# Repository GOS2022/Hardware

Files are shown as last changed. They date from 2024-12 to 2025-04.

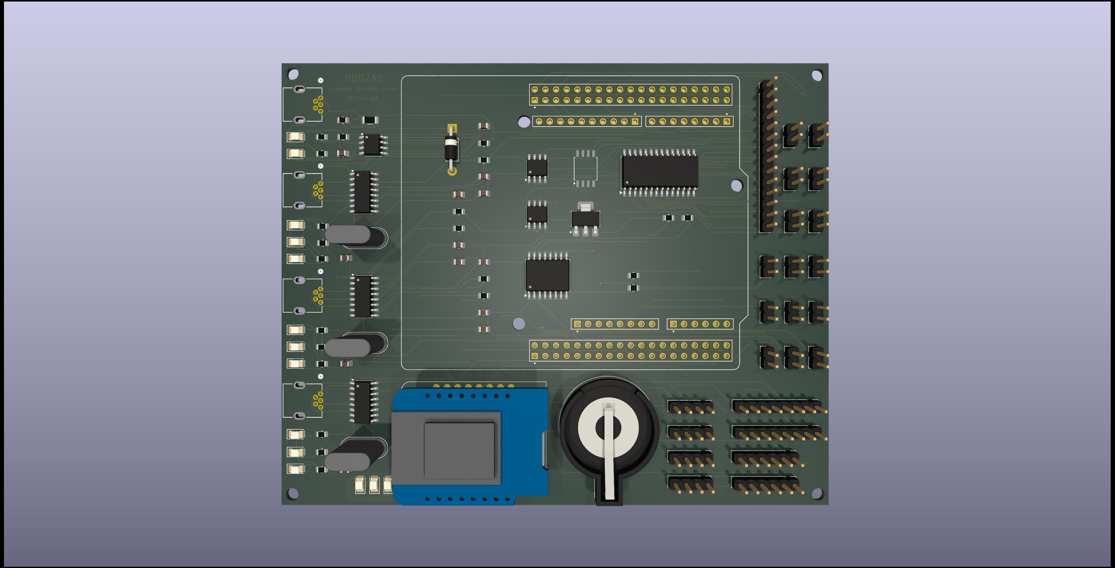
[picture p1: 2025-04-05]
MB02A1/03_Production/mb02a1_pcb_3d.jpg

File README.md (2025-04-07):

# Hardware
This repository contains the design and production files of hardware projects.

# Description
The main goal of hardware projects is to create a compact test device for the OS and service tests.

# Remarks
Contribution to this project is encouraged and appriciated.
If you have any questions or ideas, feel free to contact me: ahmedibrahim.gazar97@gmail.com

Last updated: 2025-04-07
(c) 2025, Ahmed Gazar

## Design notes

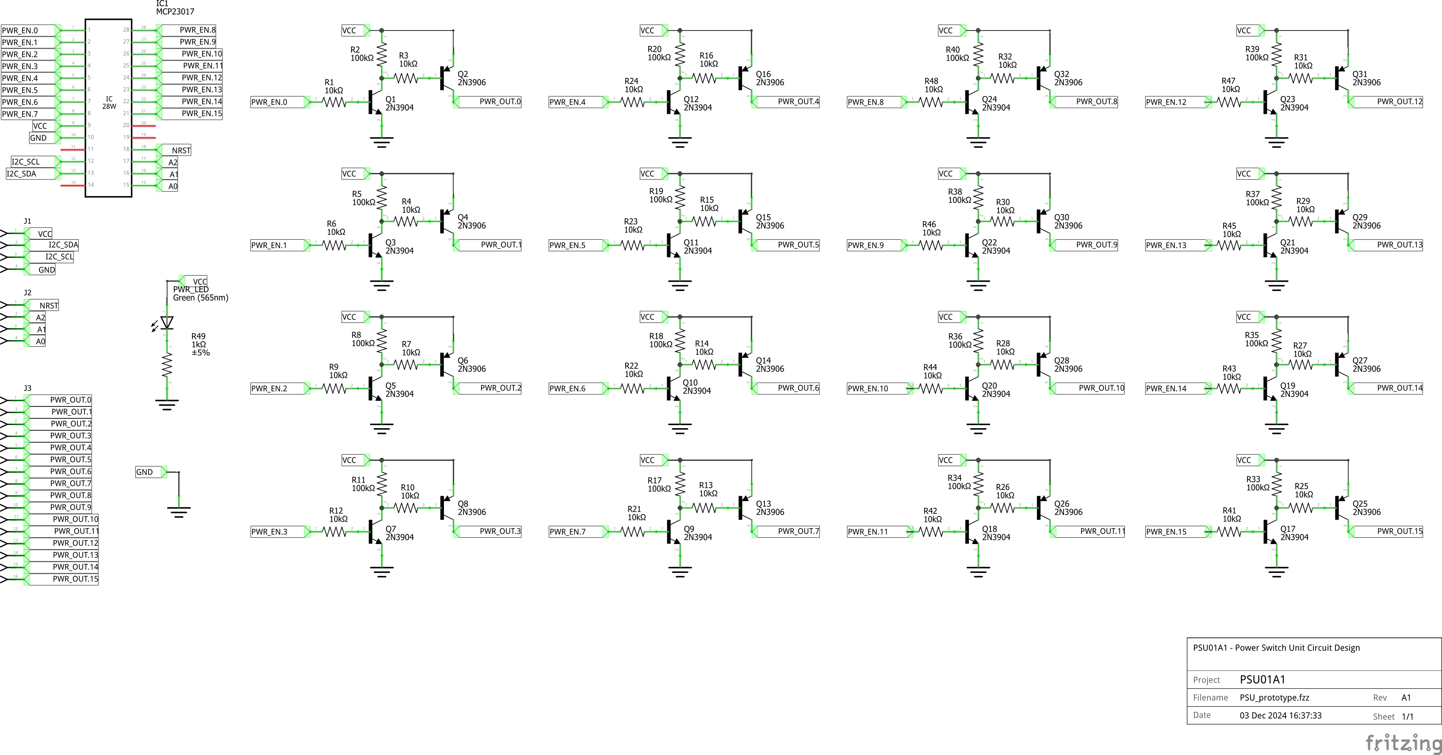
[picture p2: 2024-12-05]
MB02A1/02_Prototyping_phase/PowerSwitchUnit_prototype/Schematic.png

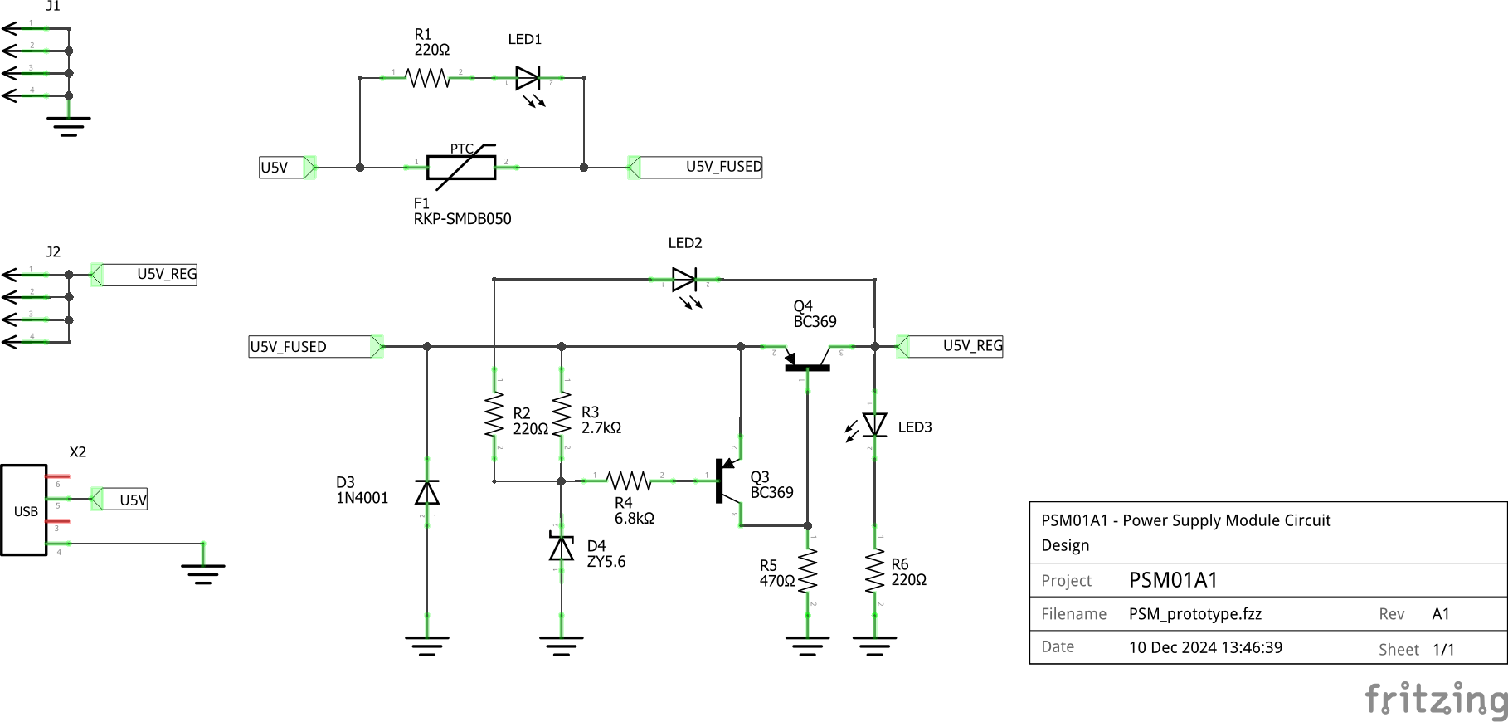
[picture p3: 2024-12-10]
MB02A1/02_Prototyping_phase/PowerSupplyModule_prototype/Schematic.png

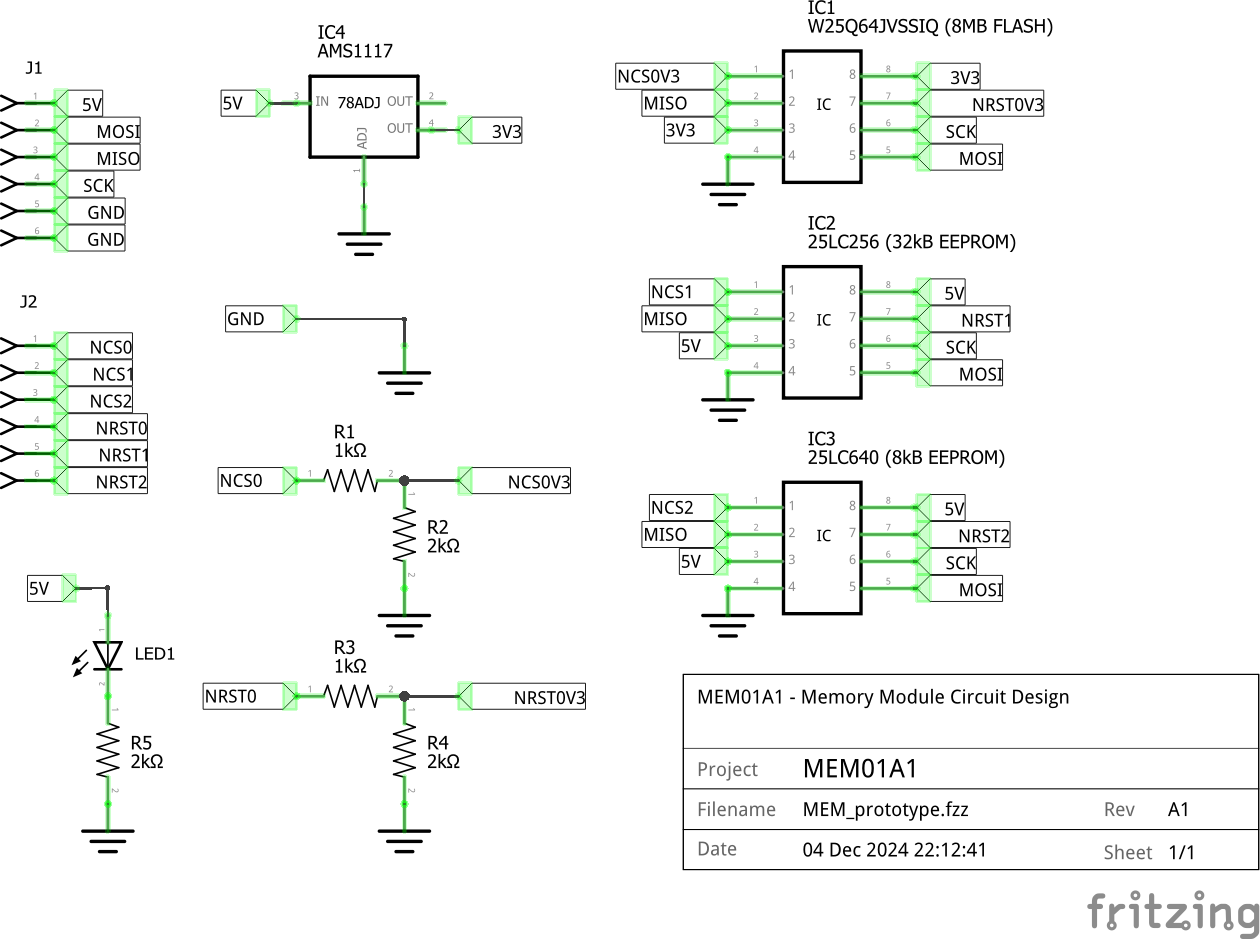
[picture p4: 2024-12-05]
MB02A1/02_Prototyping_phase/MemoryModule_prototype/Schematic.png

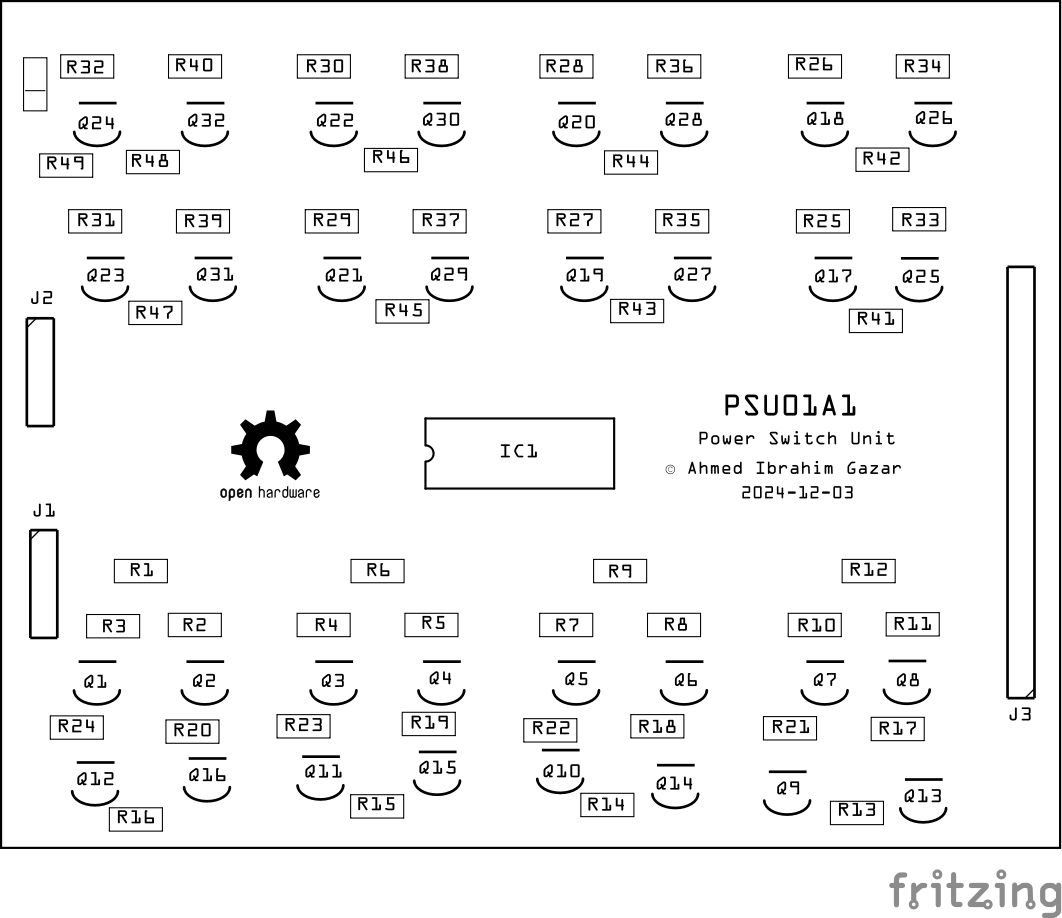
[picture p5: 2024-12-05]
MB02A1/02_Prototyping_phase/PowerSwitchUnit_prototype/PCB_SilkScreenTop.png

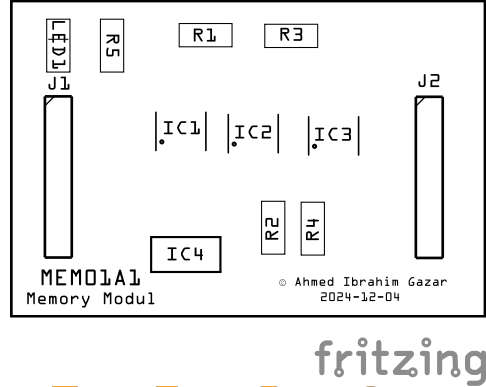
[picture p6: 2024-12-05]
MB02A1/02_Prototyping_phase/MemoryModule_prototype/PCB_SilkScreenTop.png

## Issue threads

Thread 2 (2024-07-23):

Main Board bugfix

agazar97, 2024-07-23:
Main Board (MB02A1) shall be developed based on the design of MB01A1 with the following requirements:
- MB02A1 shall reuse elements of MB01A1 but cannot contain through-hole components (all components shall be surface mounted)
- MB02A1 shall reduce size compared to MB01A1
- MB02A1 shall only have one on-board IO extender instead of two, and the connector pin header type shall be replaced with a standard-distance one (MCP23017)
- MB02A1 shall only have one on-board FLASH memory chip instead of two (24LC256)
- MB02A1 shall have the I2C2 line fixed (it is not working on MB01A1)
- MB02A1 shall feature power line switches on all peripheries (VCC shall be controllable (on/off) for MCP23017, 24LC256, WeMos D1 mini, and display).
- MB02A1 shall not have pin header connectors for UART lines
- MB02A1 shall fix the issue with USART2 line
- MB02A1 shall fix the issue with UART power line feedback LEDs (they should only light up when a cable is connected)

Closed 2025-07-29.

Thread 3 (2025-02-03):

Power supply circuit test and rework (voltage drop issue)

gaborr971, 2025-02-03:

gaborr971, 2025-03-21:
Redesign is needed (simplification).

Closed 2025-03-21.

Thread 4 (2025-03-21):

Wemos trace output test (software serial)

gaborr971, 2025-03-21:

gaborr971, 2025-03-21:
Software serial added to pins D1 and D2. With an external converter, functionality has been tested. This configuration shall be used for new main board revision.

Closed 2025-03-22.

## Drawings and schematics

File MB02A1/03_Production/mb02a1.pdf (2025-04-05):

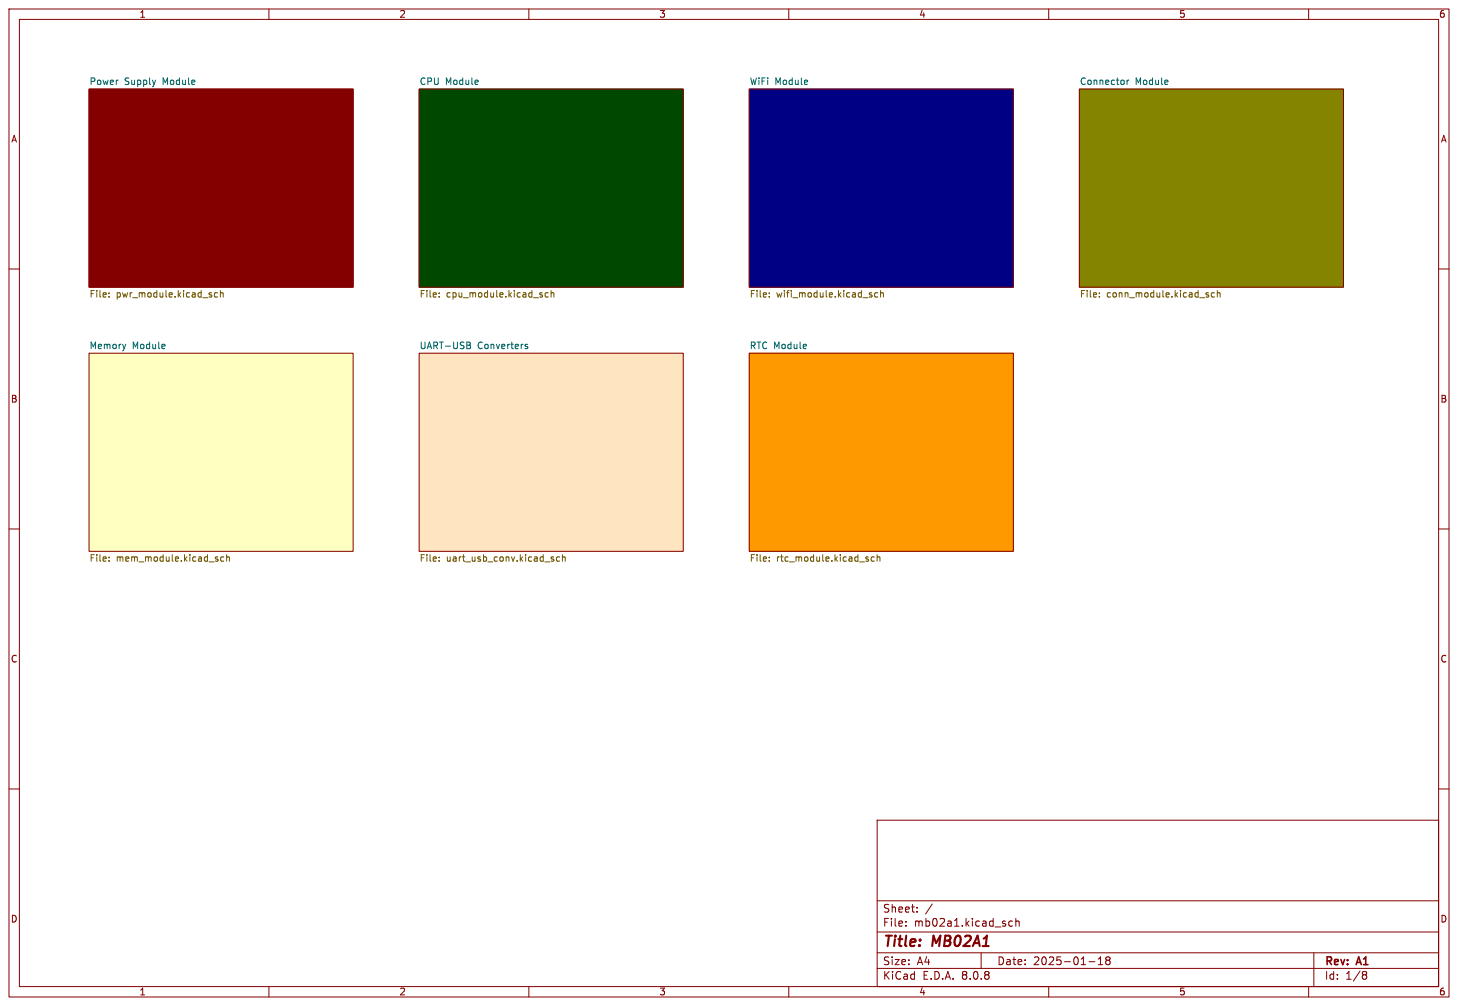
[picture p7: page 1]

Power Supply Module File: pwr_module.kicad_sch

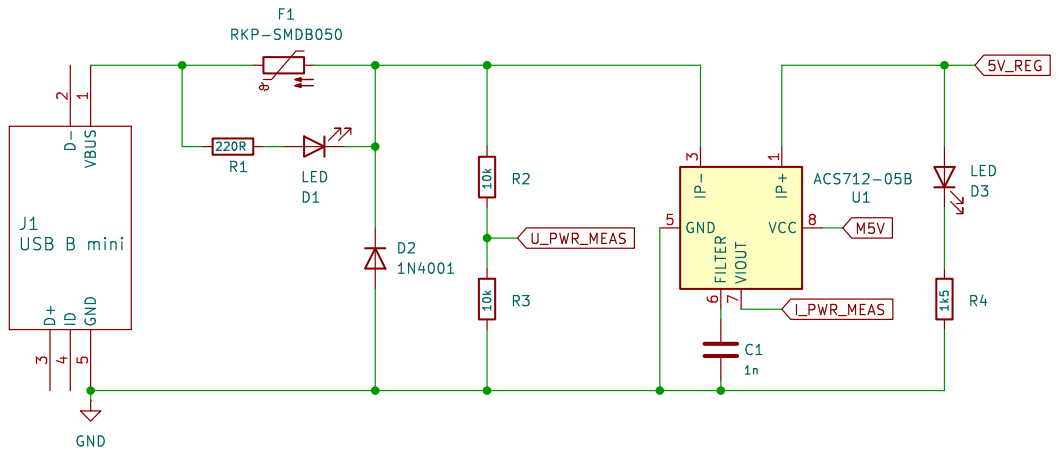
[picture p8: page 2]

Id: 2/8 Title: MB02A1 - Power Supply Module

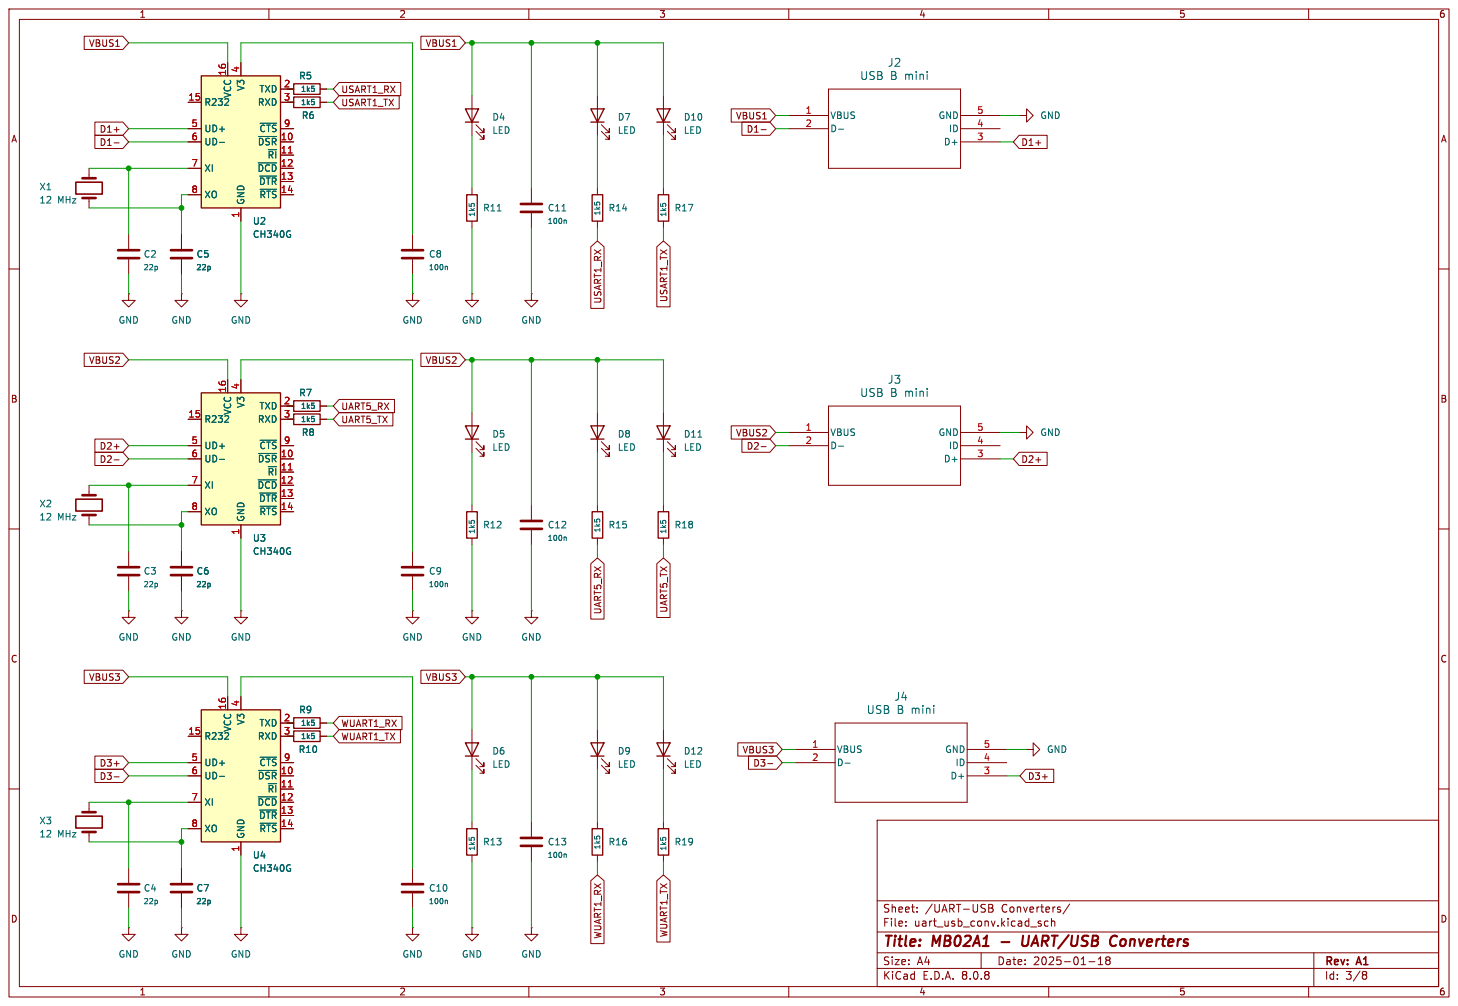
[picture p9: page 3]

Id: 3/8 Title: MB02A1 - UART/USB Converters

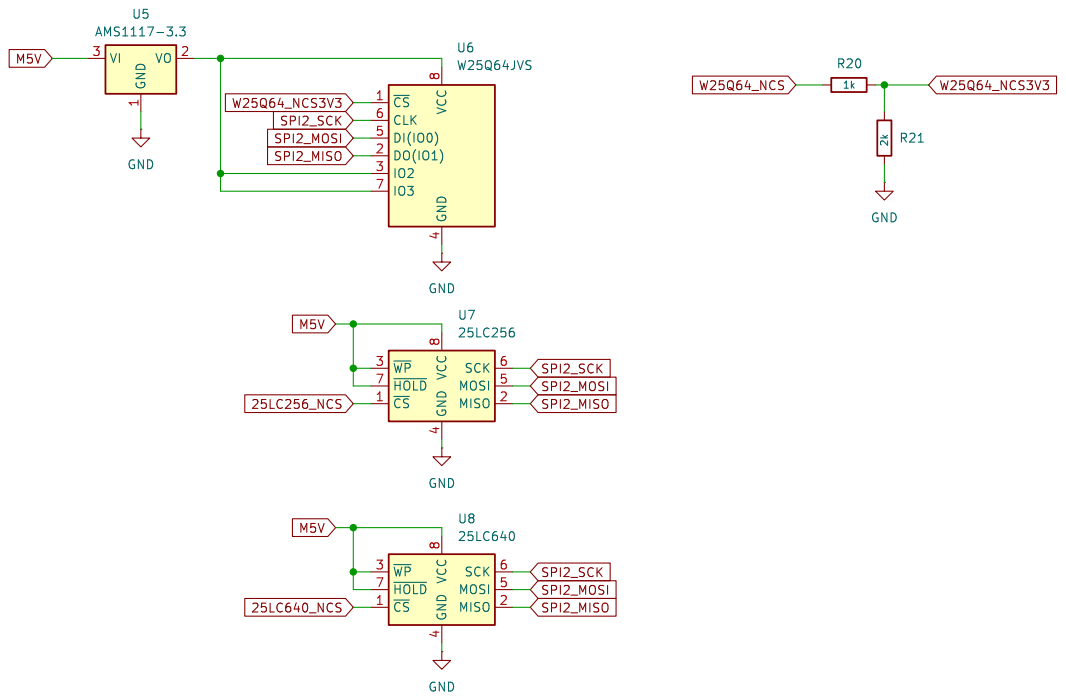
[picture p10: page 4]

1 VO 2 VI 3 U5 AMS1117-3.3 ~{CS} 1 MISO 2 ~{WP} 3 GND
SPI2_MISO W25Q64_NCS3V3 SPI2_MOSI M5V M5V

4 MOSI 5 SCK 6 ~{HOLD} 7 VCC

Id: 4/8 Title: MB02A1 - Memory Module

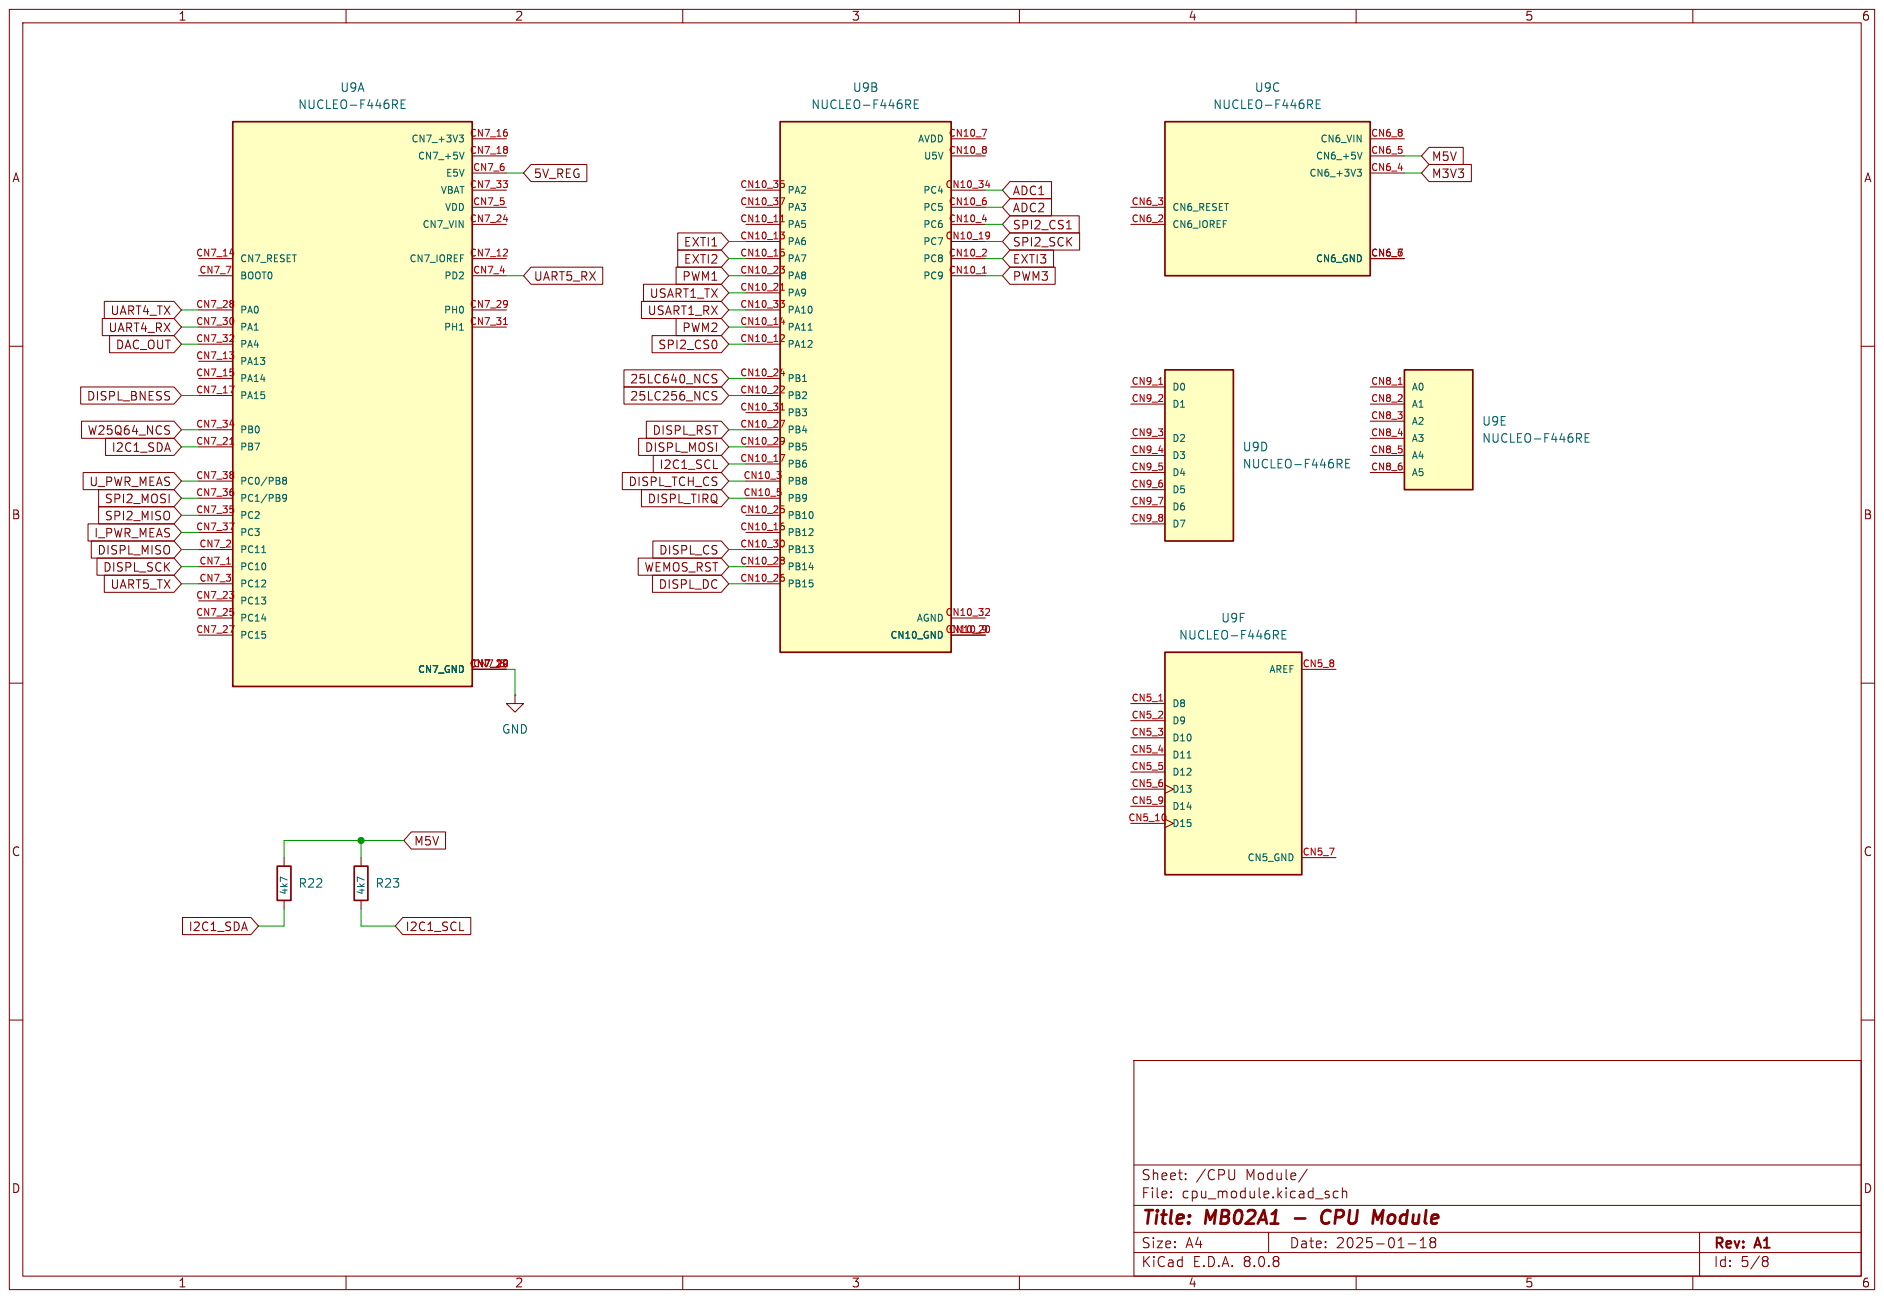
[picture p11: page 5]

Id: 5/8 Title: MB02A1 - CPU Module

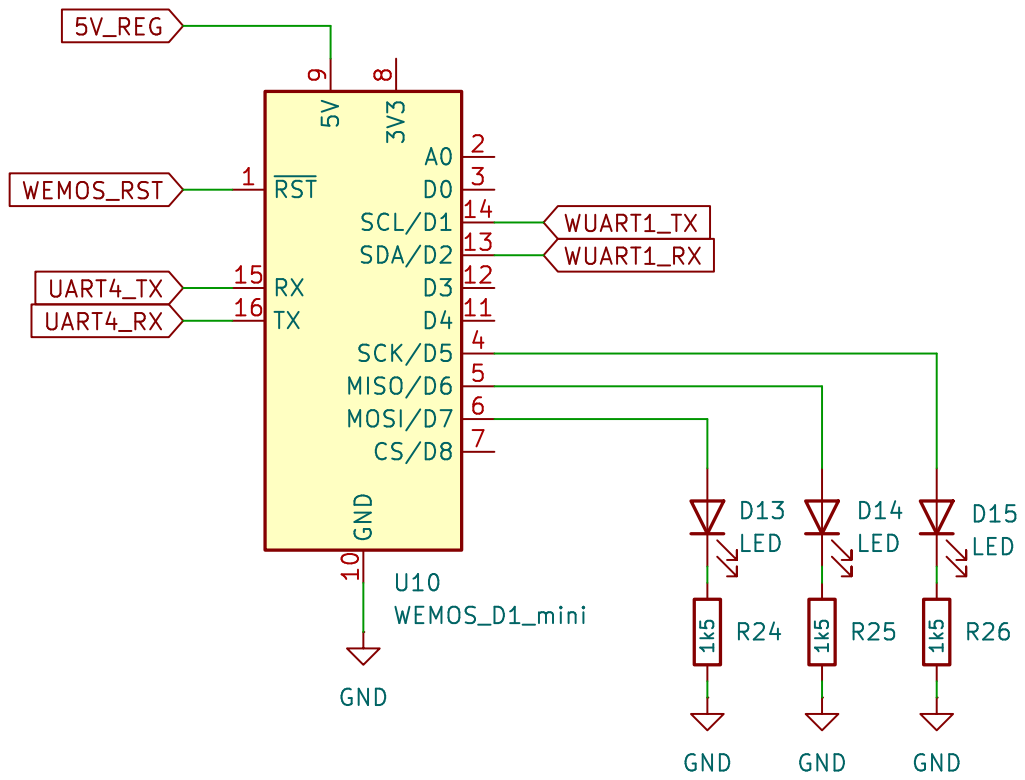
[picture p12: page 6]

Id: 6/8 Title: MB02A1 - WiFi Module

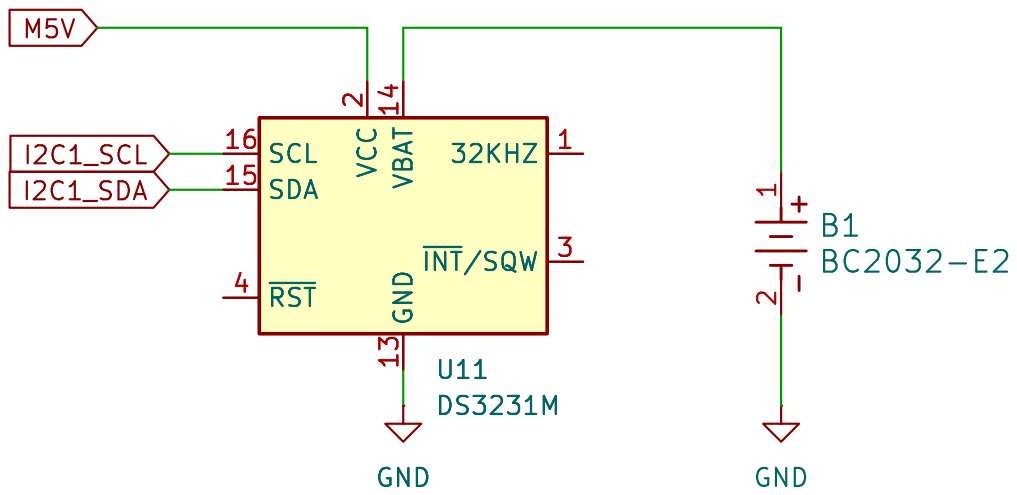
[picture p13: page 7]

Id: 7/8 Title: MB02A1 - RTC Module

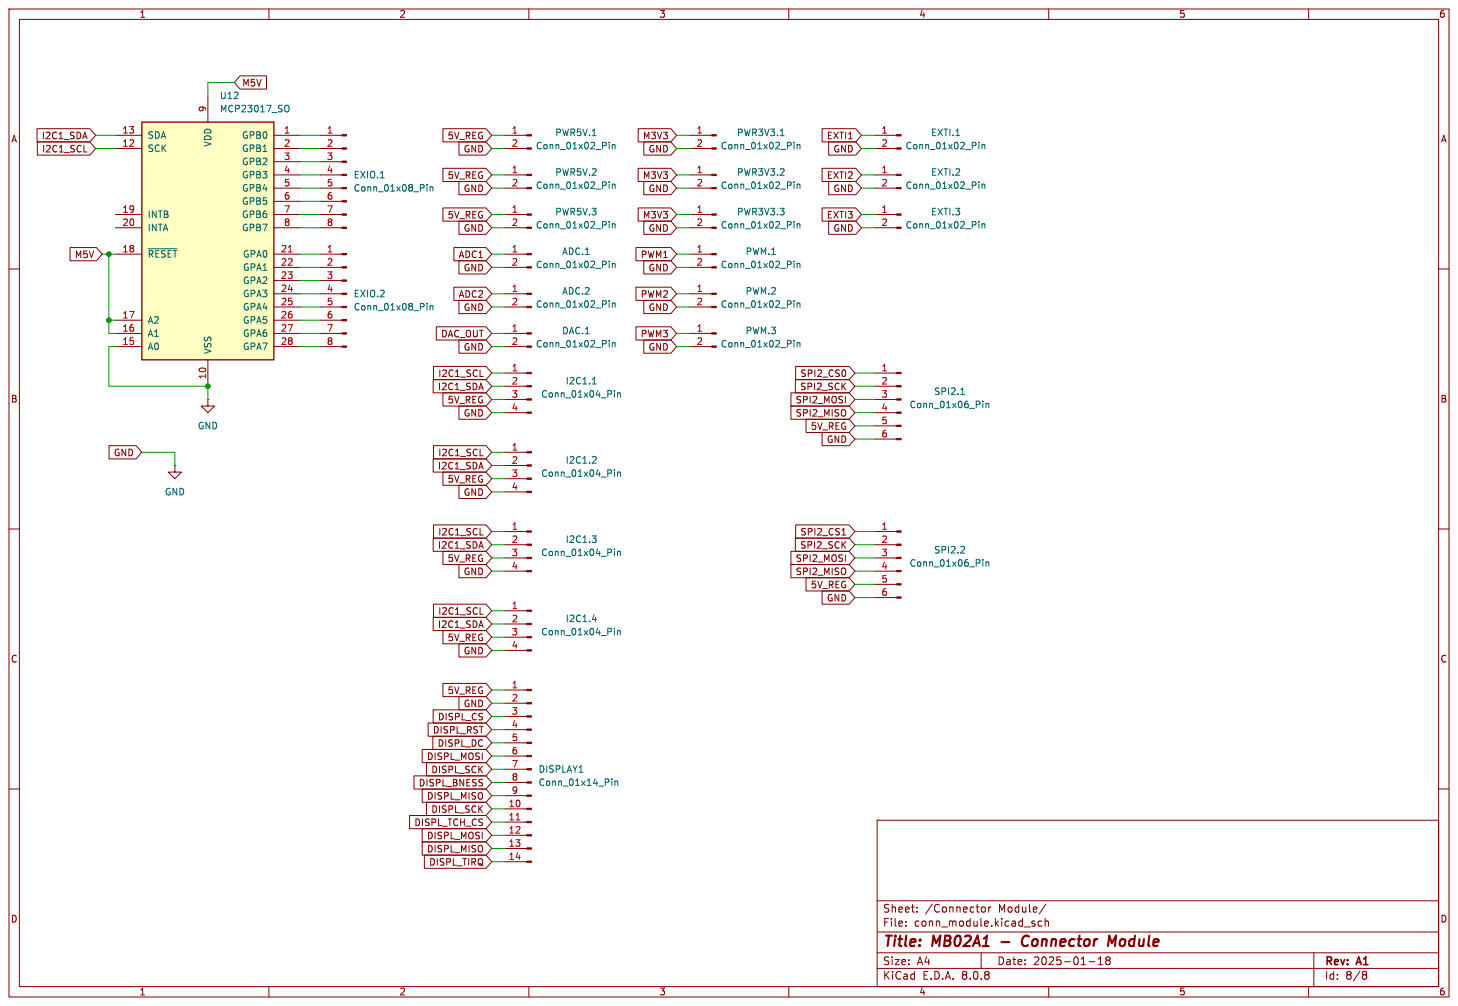
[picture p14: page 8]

GND GND M3V3 GND GND

Id: 8/8 Title: MB02A1 - Connector Module

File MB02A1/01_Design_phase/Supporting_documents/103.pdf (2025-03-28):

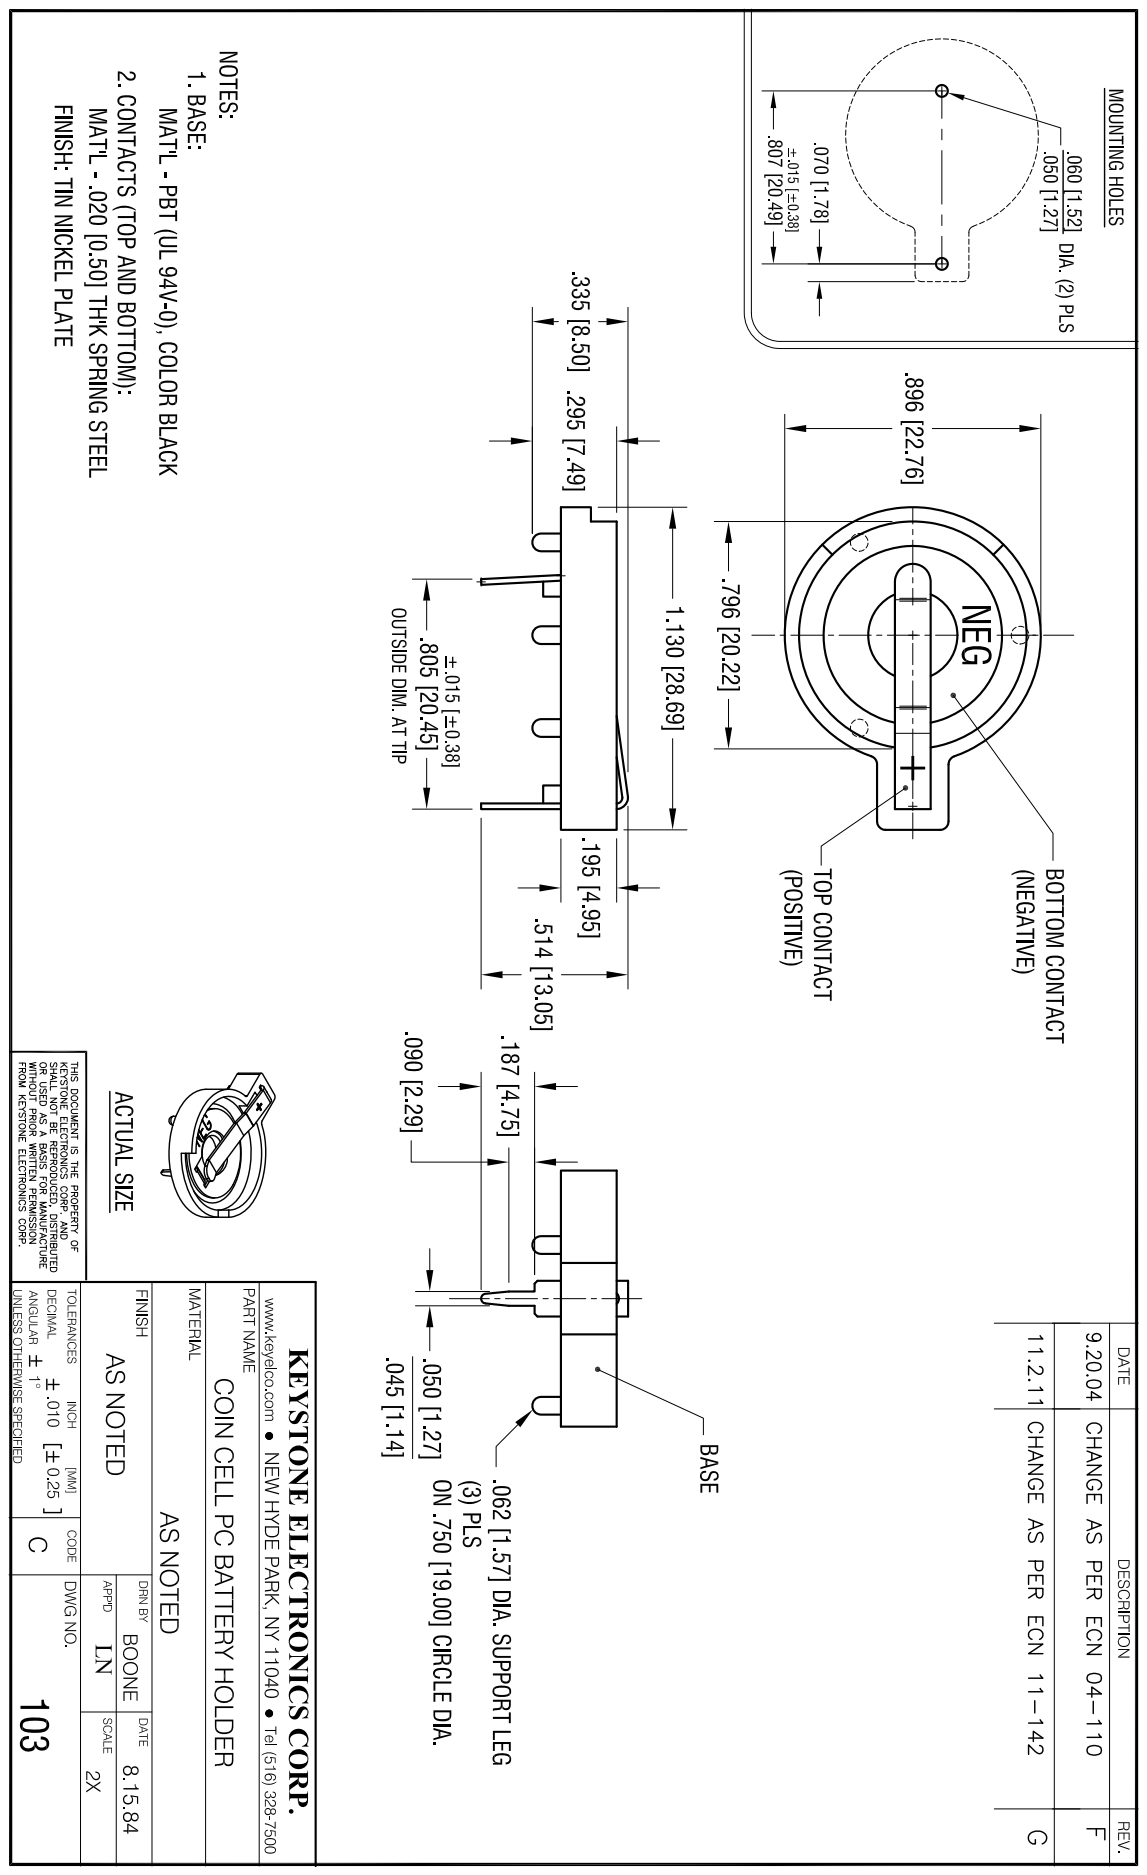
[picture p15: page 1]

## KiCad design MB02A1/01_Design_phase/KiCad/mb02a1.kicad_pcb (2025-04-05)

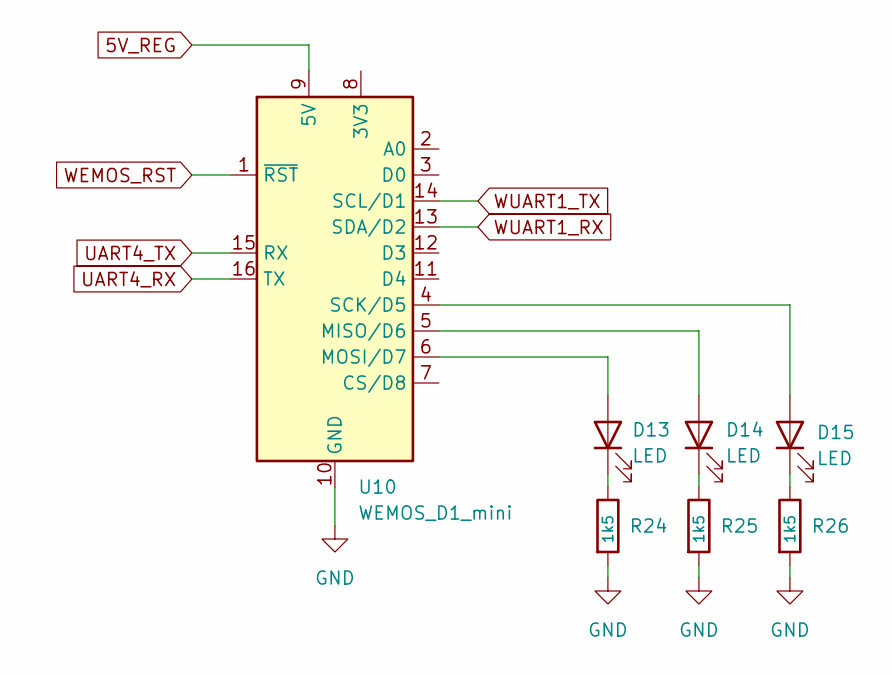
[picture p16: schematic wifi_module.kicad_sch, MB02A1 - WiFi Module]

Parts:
D13, D14, D15: LED; LED_1206_3216Metric
R24, R25, R26: 1k5; R_0805_2012Metric
U10: WEMOS_D1_mini; WEMOS_D1_mini_light

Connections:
5V_REG: U10.9 (5V); also elsewhere on the board
GND: R24.2, R25.2, R26.2, U10.10 (GND); also elsewhere on the board
unnamed: D13.2 (A), U10.6 (MOSI/D7)
unnamed: D13.1 (K), R24.1
unnamed: D14.2 (A), U10.5 (MISO/D6)
unnamed: D14.1 (K), R25.1
unnamed: D15.2 (A), U10.4 (SCK/D5)
unnamed: D15.1 (K), R26.1
UART4_RX: U10.16 (TX); also elsewhere on the board
UART4_TX: U10.15 (RX); also elsewhere on the board
WEMOS_RST: U10.1 (~RST); also elsewhere on the board
WUART1_RX: U10.13 (SDA/D2); also elsewhere on the board
WUART1_TX: U10.14 (SCL/D1); also elsewhere on the board

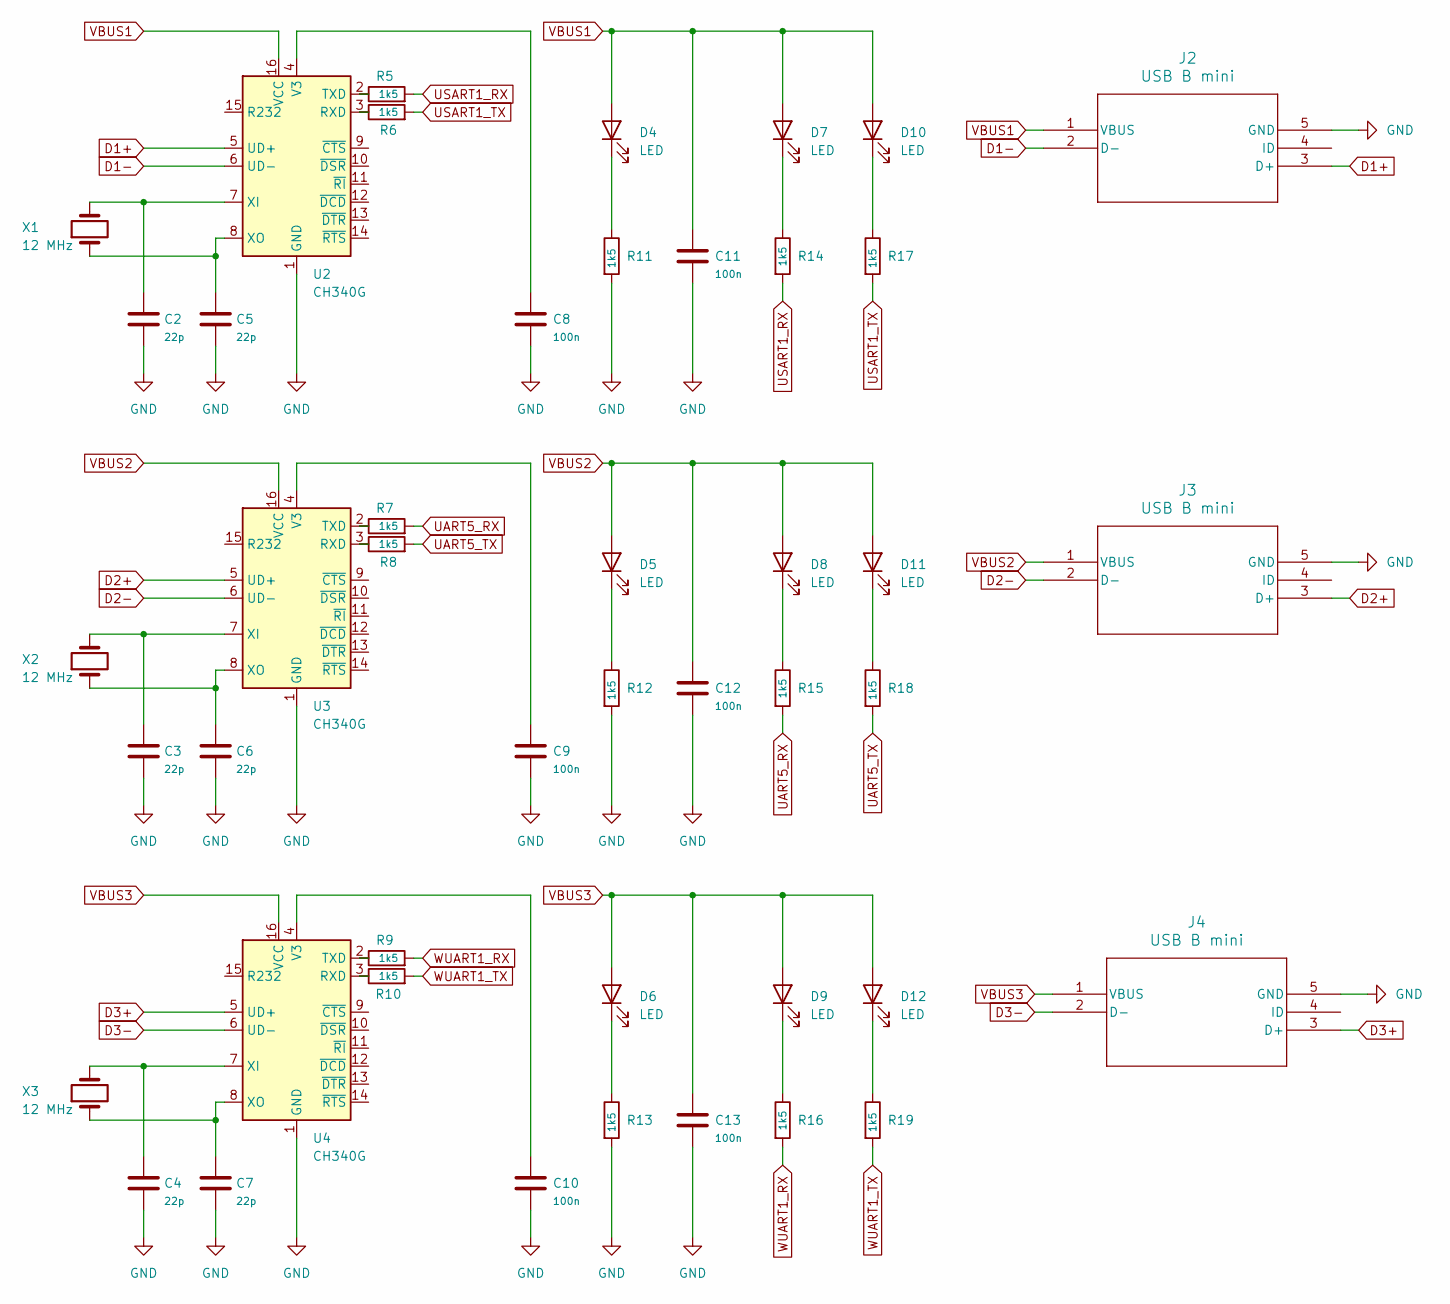
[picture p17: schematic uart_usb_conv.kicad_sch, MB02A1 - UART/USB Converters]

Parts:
C2, C3, C4, C5, C6, C7: 22p; C_0805_2012Metric
C8, C9, C10, C11, C12, C13: 100n; C_0805_2012Metric
D4, D5, D6, D7, D8, D9, D10, D11, D12: LED; LED_1206_3216Metric
J2, J3, J4: USB B mini; 54819-0519_MOL
R5, R6, R7, R8, R9, R10, R11, R12, R13, R14, R15, R16, R17, R18, R19: 1k5; R_0805_2012Metric
U2, U3, U4: CH340G; SOIC-16_3.9x9.9mm_P1.27mm
X1, X2, X3: 12 MHz; Crystal_HC49-U_Vertical

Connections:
D1+: J2.3 (D+), U2.5 (UD+)
D1-: J2.2 (D-), U2.6 (UD-)
D2+: J3.3 (D+), U3.5 (UD+)
D2-: J3.2 (D-), U3.6 (UD-)
D3+: J4.3 (D+), U4.5 (UD+)
D3-: J4.2 (D-), U4.6 (UD-)
GND: C2.2, C3.2, C4.2, C5.2, C6.2, C7.2, C8.2, C9.2, C10.2, C11.2, C12.2, C13.2, J2.5 (GND), J3.5 (GND), J4.5 (GND), R11.2, R12.2, R13.2, U2.1 (GND), U3.1 (GND), U4.1 (GND); also elsewhere on the board
unnamed: D4.1 (K), R11.1
unnamed: D5.1 (K), R12.1
unnamed: D6.1 (K), R13.1
unnamed: D7.1 (K), R14.1
unnamed: D8.1 (K), R15.1
unnamed: D9.1 (K), R16.1
unnamed: D10.1 (K), R17.1
unnamed: D11.1 (K), R18.1
unnamed: D12.1 (K), R19.1
unnamed: R6.1, U2.3 (RXD)
unnamed: R5.1, U2.2 (TXD)
unnamed: C8.1, U2.4 (V3)
unnamed: C2.1, U2.7 (XI), X1.2
unnamed: C5.1, U2.8 (XO), X1.1
unnamed: R8.1, U3.3 (RXD)
unnamed: R7.1, U3.2 (TXD)
unnamed: C9.1, U3.4 (V3)
unnamed: C3.1, U3.7 (XI), X2.2
unnamed: C6.1, U3.8 (XO), X2.1
unnamed: R10.1, U4.3 (RXD)
unnamed: R9.1, U4.2 (TXD)
unnamed: C10.1, U4.4 (V3)
unnamed: C4.1, U4.7 (XI), X3.2
unnamed: C7.1, U4.8 (XO), X3.1
UART5_RX: R7.2, R15.2; also elsewhere on the board
UART5_TX: R8.2, R18.2; also elsewhere on the board
USART1_RX: R5.2, R14.2; also elsewhere on the board
USART1_TX: R6.2, R17.2; also elsewhere on the board
VBUS1: C11.1, D4.2 (A), D7.2 (A), D10.2 (A), J2.1 (VBUS), U2.16 (VCC)
VBUS2: C12.1, D5.2 (A), D8.2 (A), D11.2 (A), J3.1 (VBUS), U3.16 (VCC)
VBUS3: C13.1, D6.2 (A), D9.2 (A), D12.2 (A), J4.1 (VBUS), U4.16 (VCC)
WUART1_RX: R9.2, R16.2; also elsewhere on the board
WUART1_TX: R10.2, R19.2; also elsewhere on the board

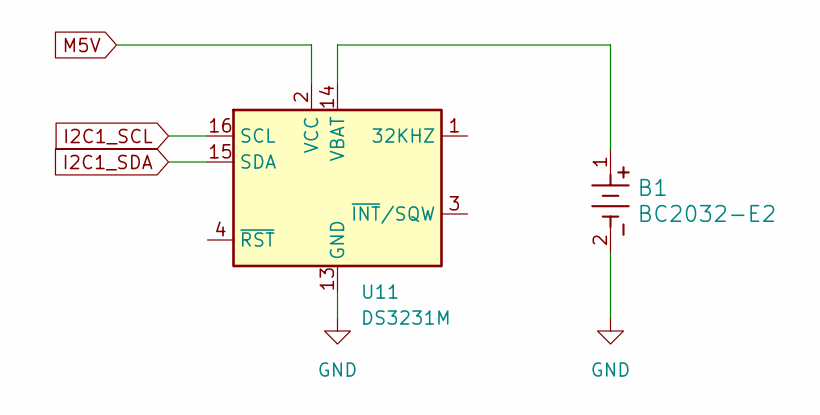
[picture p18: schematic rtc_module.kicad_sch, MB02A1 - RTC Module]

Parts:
B1: BC2032-E2; BC2032-E2_MPD
U11: DS3231M; SOIC-16W_7.5x10.3mm_P1.27mm

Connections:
GND: B1.2, U11.5 (GND), U11.6 (GND), U11.7 (GND), U11.8 (GND), U11.9 (GND), U11.10 (GND), U11.11 (GND), U11.12 (GND), U11.13 (GND); also elsewhere on the board
I2C1_SCL: U11.16 (SCL); also elsewhere on the board
I2C1_SDA: U11.15 (SDA); also elsewhere on the board
M5V: U11.2 (VCC); also elsewhere on the board
unnamed: B1.1, U11.14 (VBAT)

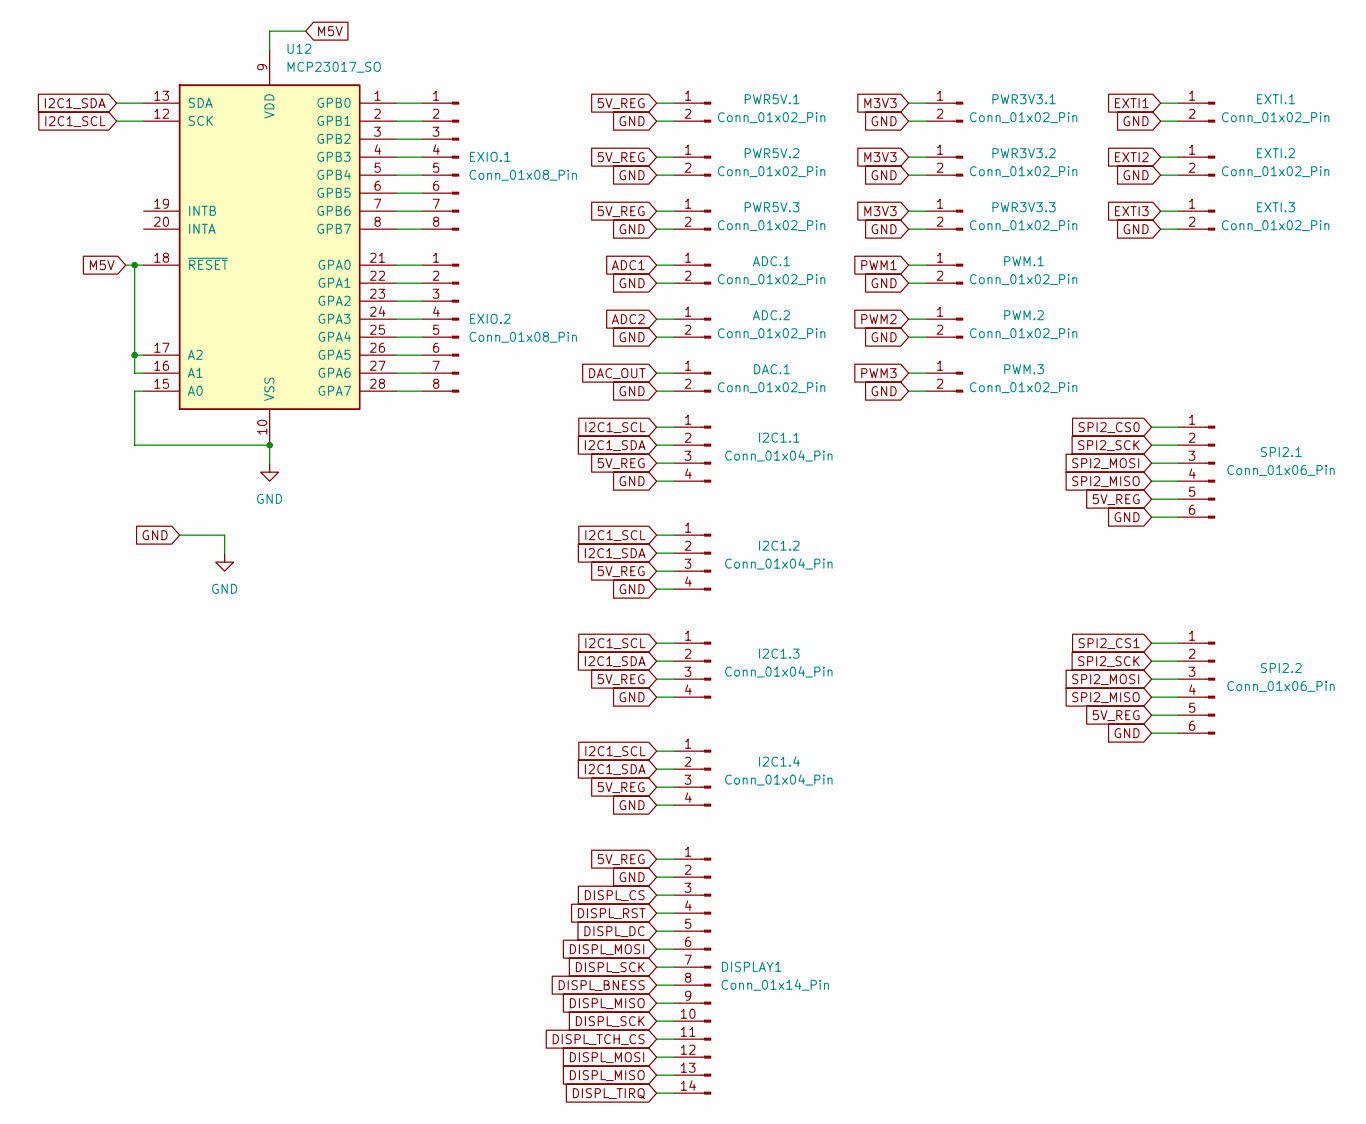
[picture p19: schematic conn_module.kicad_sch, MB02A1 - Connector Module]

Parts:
ADC.1, ADC.2: Conn_01x02_Pin; PinHeader_1x02_P2.54mm_Vertical
DAC.1: Conn_01x02_Pin; PinHeader_1x02_P2.54mm_Vertical
DISPLAY1: Conn_01x14_Pin; PinHeader_1x14_P2.54mm_Vertical
EXIO.1, EXIO.2: Conn_01x08_Pin; PinHeader_1x08_P2.54mm_Vertical
EXTI.1, EXTI.2, EXTI.3: Conn_01x02_Pin; PinHeader_1x02_P2.54mm_Vertical
I2C1.1, I2C1.2, I2C1.3, I2C1.4: Conn_01x04_Pin; PinHeader_1x04_P2.54mm_Vertical
PWM.1, PWM.2, PWM.3: Conn_01x02_Pin; PinHeader_1x02_P2.54mm_Vertical
PWR3V3.1, PWR3V3.2, PWR3V3.3, PWR5V.1, PWR5V.2, PWR5V.3: Conn_01x02_Pin; PinHeader_1x02_P2.54mm_Vertical
SPI2.1, SPI2.2: Conn_01x06_Pin; PinHeader_1x06_P2.54mm_Vertical
U12: MCP23017_SO; SOIC-28W_7.5x17.9mm_P1.27mm

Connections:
5V_REG: DISPLAY1.1, I2C1.1.3, I2C1.2.3, I2C1.3.3, I2C1.4.3, PWR5V.1.1, PWR5V.2.1, PWR5V.3.1, SPI2.1.5, SPI2.2.5; also elsewhere on the board
ADC1: ADC.1.1; also elsewhere on the board
ADC2: ADC.2.1; also elsewhere on the board
DAC_OUT: DAC.1.1; also elsewhere on the board
DISPL_BNESS: DISPLAY1.8; also elsewhere on the board
DISPL_CS: DISPLAY1.3; also elsewhere on the board
DISPL_DC: DISPLAY1.5; also elsewhere on the board
DISPL_MISO: DISPLAY1.9, DISPLAY1.13; also elsewhere on the board
DISPL_MOSI: DISPLAY1.6, DISPLAY1.12; also elsewhere on the board
DISPL_RST: DISPLAY1.4; also elsewhere on the board
DISPL_SCK: DISPLAY1.7, DISPLAY1.10; also elsewhere on the board
DISPL_TCH_CS: DISPLAY1.11; also elsewhere on the board
DISPL_TIRQ: DISPLAY1.14; also elsewhere on the board
EXTI1: EXTI.1.1; also elsewhere on the board
EXTI2: EXTI.2.1; also elsewhere on the board
EXTI3: EXTI.3.1; also elsewhere on the board
GND: ADC.1.2, ADC.2.2, DAC.1.2, DISPLAY1.2, EXTI.1.2, EXTI.2.2, EXTI.3.2, I2C1.1.4, I2C1.2.4, I2C1.3.4, I2C1.4.4, PWM.1.2, PWM.2.2, PWM.3.2, PWR3V3.1.2, PWR3V3.2.2, PWR3V3.3.2, PWR5V.1.2, PWR5V.2.2, PWR5V.3.2, SPI2.1.6, SPI2.2.6, U12.10 (VSS), U12.15 (A0); also elsewhere on the board
I2C1_SCL: I2C1.1.1, I2C1.2.1, I2C1.3.1, I2C1.4.1, U12.12 (SCK); also elsewhere on the board
I2C1_SDA: I2C1.1.2, I2C1.2.2, I2C1.3.2, I2C1.4.2, U12.13 (SDA); also elsewhere on the board
M3V3: PWR3V3.1.1, PWR3V3.2.1, PWR3V3.3.1; also elsewhere on the board
M5V: U12.9 (VDD), U12.16 (A1), U12.17 (A2), U12.18 (~RESET); also elsewhere on the board
unnamed: EXIO.1.1, U12.1 (GPB0)
unnamed: EXIO.1.2, U12.2 (GPB1)
unnamed: EXIO.1.3, U12.3 (GPB2)
unnamed: EXIO.1.4, U12.4 (GPB3)
unnamed: EXIO.1.5, U12.5 (GPB4)
unnamed: EXIO.1.6, U12.6 (GPB5)
unnamed: EXIO.1.7, U12.7 (GPB6)
unnamed: EXIO.1.8, U12.8 (GPB7)
unnamed: EXIO.2.1, U12.21 (GPA0)
unnamed: EXIO.2.2, U12.22 (GPA1)
unnamed: EXIO.2.3, U12.23 (GPA2)
unnamed: EXIO.2.4, U12.24 (GPA3)
unnamed: EXIO.2.5, U12.25 (GPA4)
unnamed: EXIO.2.6, U12.26 (GPA5)
unnamed: EXIO.2.7, U12.27 (GPA6)
unnamed: EXIO.2.8, U12.28 (GPA7)
PWM1: PWM.1.1; also elsewhere on the board
PWM2: PWM.2.1; also elsewhere on the board
PWM3: PWM.3.1; also elsewhere on the board
SPI2_CS0: SPI2.1.1; also elsewhere on the board
SPI2_CS1: SPI2.2.1; also elsewhere on the board
SPI2_MISO: SPI2.1.4, SPI2.2.4; also elsewhere on the board
SPI2_MOSI: SPI2.1.3, SPI2.2.3; also elsewhere on the board
SPI2_SCK: SPI2.1.2, SPI2.2.2; also elsewhere on the board

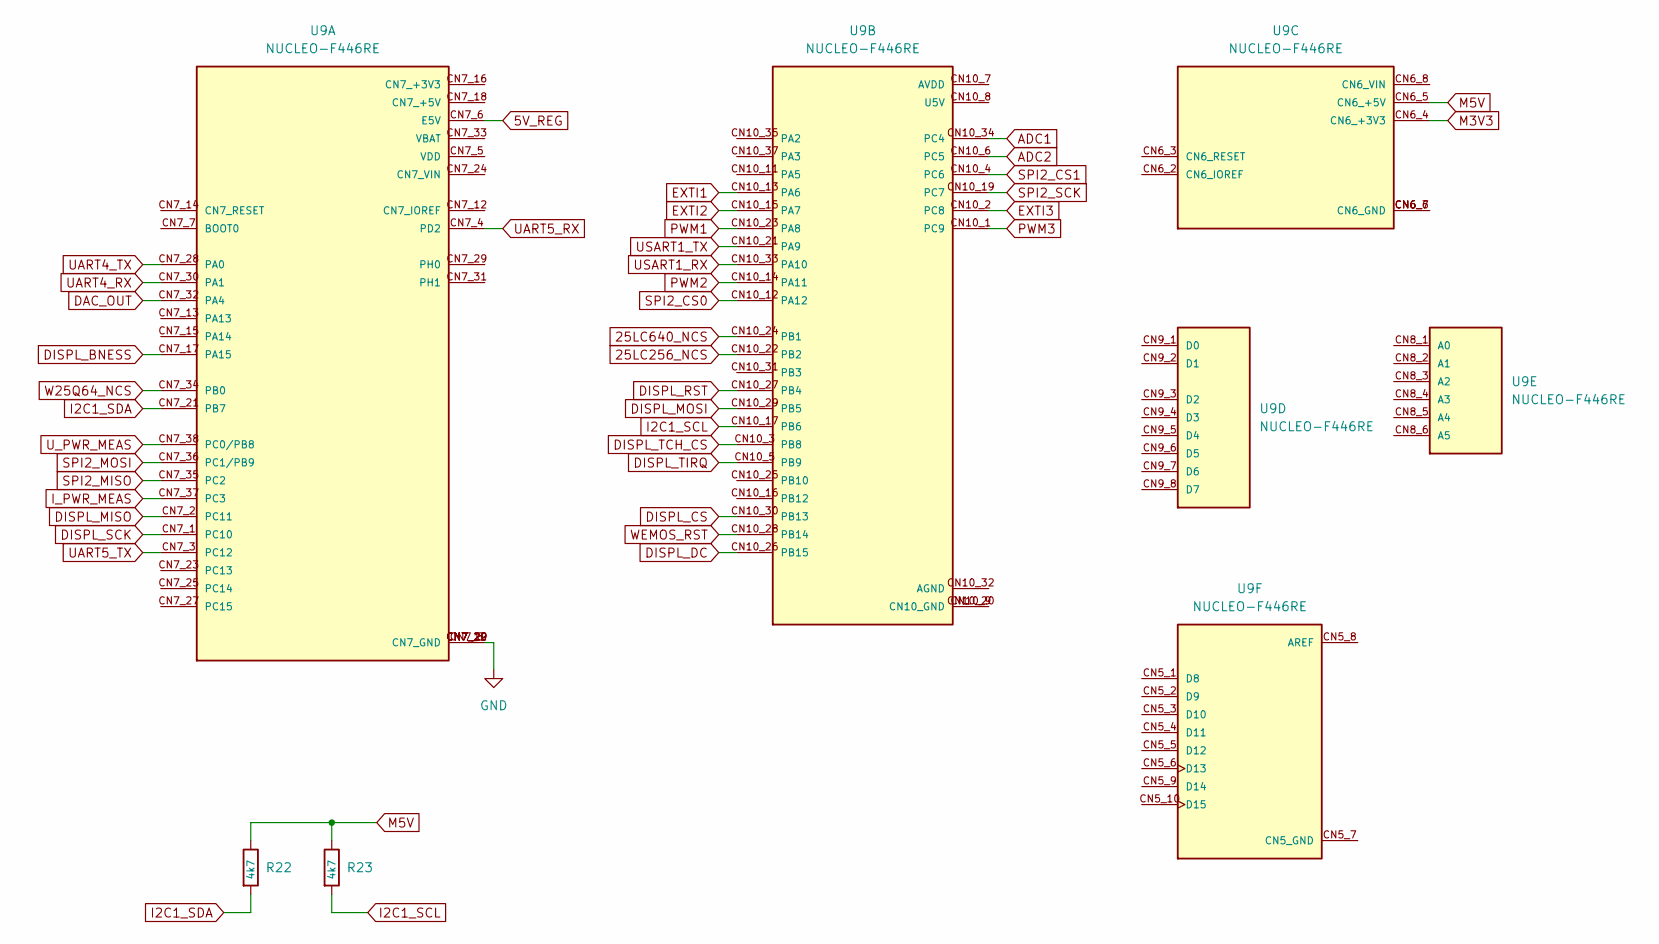
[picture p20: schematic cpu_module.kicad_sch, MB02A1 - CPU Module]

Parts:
R22, R23: 4k7; R_0805_2012Metric
U9: NUCLEO-F446RE; MODULE_NUCLEO-F446RE; PARTREV 13; DigiKey_Part_Number 497-15882-ND

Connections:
5V_REG: U9.CN7_6 (E5V); also elsewhere on the board
25LC256_NCS: U9.CN10_22 (PB2); also elsewhere on the board
25LC640_NCS: U9.CN10_24 (PB1); also elsewhere on the board
ADC1: U9.CN10_34 (PC4); also elsewhere on the board
ADC2: U9.CN10_6 (PC5); also elsewhere on the board
DAC_OUT: U9.CN7_32 (PA4); also elsewhere on the board
DISPL_BNESS: U9.CN7_17 (PA15); also elsewhere on the board
DISPL_CS: U9.CN10_30 (PB13); also elsewhere on the board
DISPL_DC: U9.CN10_26 (PB15); also elsewhere on the board
DISPL_MISO: U9.CN7_2 (PC11); also elsewhere on the board
DISPL_MOSI: U9.CN10_29 (PB5); also elsewhere on the board
DISPL_RST: U9.CN10_27 (PB4); also elsewhere on the board
DISPL_SCK: U9.CN7_1 (PC10); also elsewhere on the board
DISPL_TCH_CS: U9.CN10_3 (PB8); also elsewhere on the board
DISPL_TIRQ: U9.CN10_5 (PB9); also elsewhere on the board
EXTI1: U9.CN10_13 (PA6); also elsewhere on the board
EXTI2: U9.CN10_15 (PA7); also elsewhere on the board
EXTI3: U9.CN10_2 (PC8); also elsewhere on the board
GND: U9.CN7_8 (CN7_GND), U9.CN7_19 (CN7_GND), U9.CN7_20 (CN7_GND), U9.CN7_22 (CN7_GND); also elsewhere on the board
I2C1_SCL: R23.2, U9.CN10_17 (PB6); also elsewhere on the board
I2C1_SDA: R22.2, U9.CN7_21 (PB7); also elsewhere on the board
I_PWR_MEAS: U9.CN7_37 (PC3); also elsewhere on the board
M3V3: U9.CN6_4 (CN6_+3V3); also elsewhere on the board
M5V: R22.1, R23.1, U9.CN6_5 (CN6_+5V); also elsewhere on the board
unnamed: U9.CN10_9 (CN10_GND), U9.CN10_20 (CN10_GND)
unnamed: U9.CN6_6 (CN6_GND), U9.CN6_7 (CN6_GND)
PWM1: U9.CN10_23 (PA8); also elsewhere on the board
PWM2: U9.CN10_14 (PA11); also elsewhere on the board
PWM3: U9.CN10_1 (PC9); also elsewhere on the board
SPI2_CS0: U9.CN10_12 (PA12); also elsewhere on the board
SPI2_CS1: U9.CN10_4 (PC6); also elsewhere on the board
SPI2_MISO: U9.CN7_35 (PC2); also elsewhere on the board
SPI2_MOSI: U9.CN7_36 (PC1/PB9); also elsewhere on the board
SPI2_SCK: U9.CN10_19 (PC7); also elsewhere on the board
UART4_RX: U9.CN7_30 (PA1); also elsewhere on the board
UART4_TX: U9.CN7_28 (PA0); also elsewhere on the board
UART5_RX: U9.CN7_4 (PD2); also elsewhere on the board
UART5_TX: U9.CN7_3 (PC12); also elsewhere on the board
USART1_RX: U9.CN10_33 (PA10); also elsewhere on the board
USART1_TX: U9.CN10_21 (PA9); also elsewhere on the board
U_PWR_MEAS: U9.CN7_38 (PC0/PB8); also elsewhere on the board
W25Q64_NCS: U9.CN7_34 (PB0); also elsewhere on the board
WEMOS_RST: U9.CN10_28 (PB14); also elsewhere on the board

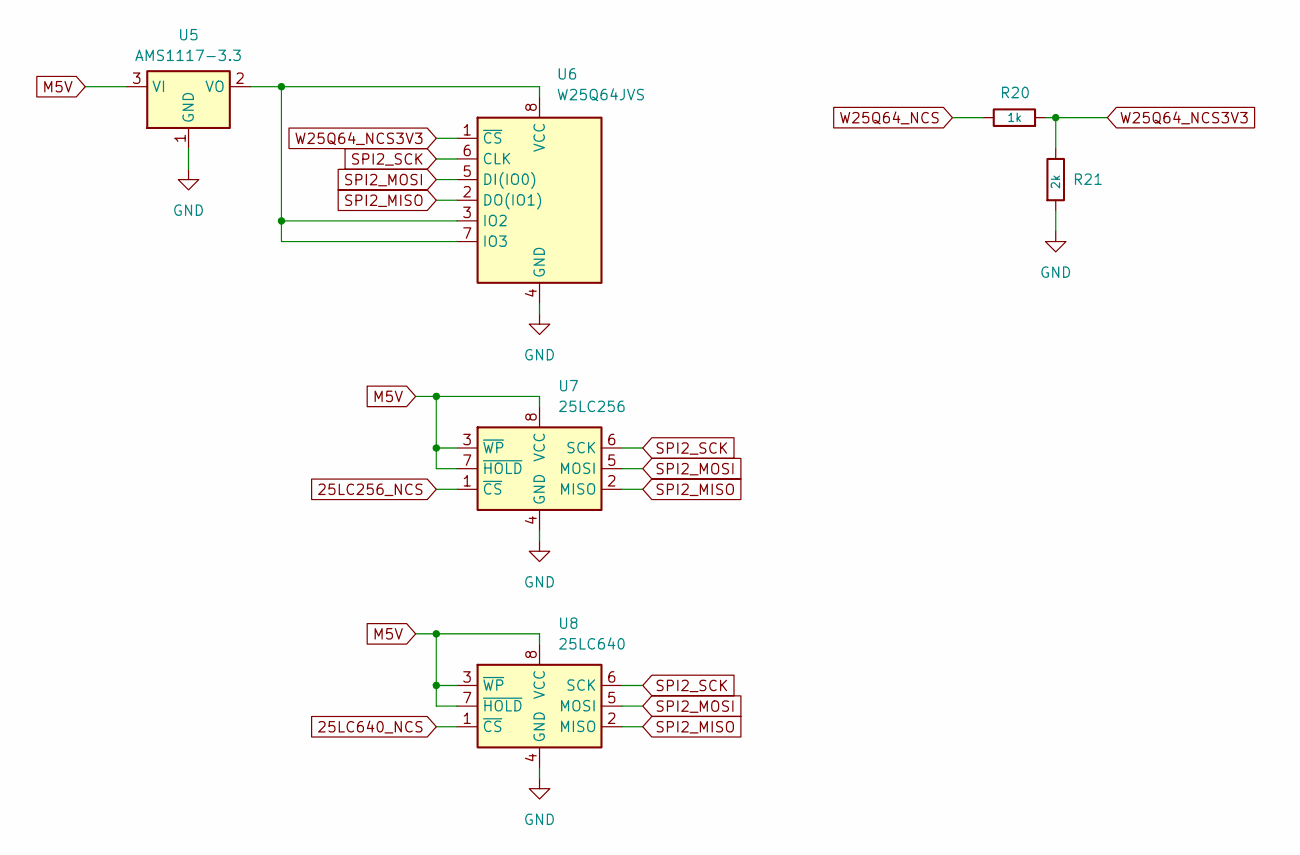
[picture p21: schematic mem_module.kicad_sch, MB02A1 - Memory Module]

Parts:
R20: 1k; R_0805_2012Metric
R21: 2k; R_0805_2012Metric
U5: AMS1117-3.3; SOT-223-3_TabPin2
U6: W25Q64JVS; SOIC-8_5.23x5.23mm_P1.27mm
U7: 25LC256; SOIC-8_3.9x4.9mm_P1.27mm
U8: 25LC640; SOIC-8_3.9x4.9mm_P1.27mm

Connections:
25LC256_NCS: U7.1 (~CS); also elsewhere on the board
25LC640_NCS: U8.1 (~CS); also elsewhere on the board
GND: R21.2, U5.1 (GND), U6.4 (GND), U7.4 (GND), U8.4 (GND); also elsewhere on the board
M5V: U5.3 (VI), U7.3 (~WP), U7.7 (~HOLD), U7.8 (VCC), U8.3 (~WP), U8.7 (~HOLD), U8.8 (VCC); also elsewhere on the board
unnamed: U5.2 (VO), U6.3 (IO2), U6.7 (IO3), U6.8 (VCC)
SPI2_MISO: U6.2 (DO(IO1)), U7.2 (MISO), U8.2 (MISO); also elsewhere on the board
SPI2_MOSI: U6.5 (DI(IO0)), U7.5 (MOSI), U8.5 (MOSI); also elsewhere on the board
SPI2_SCK: U6.6 (CLK), U7.6 (SCK), U8.6 (SCK); also elsewhere on the board
W25Q64_NCS: R20.1; also elsewhere on the board
W25Q64_NCS3V3: R20.2, R21.1, U6.1 (~CS)

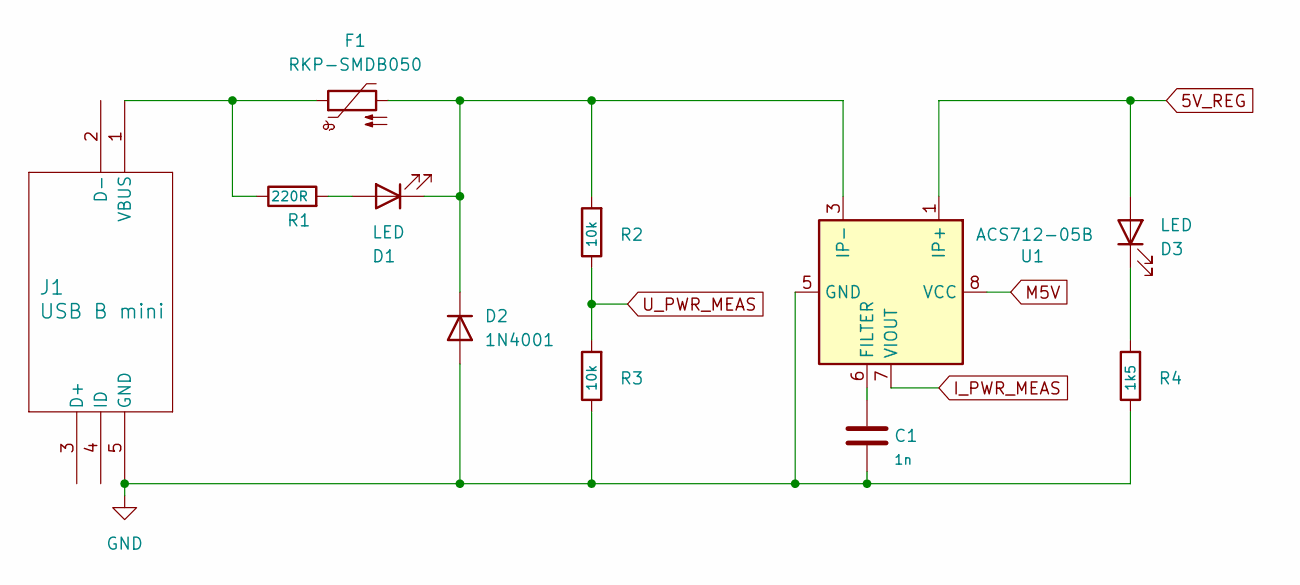
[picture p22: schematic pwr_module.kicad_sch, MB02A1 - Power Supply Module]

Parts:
C1: 1n; C_0805_2012Metric
D1, D3: LED; LED_1206_3216Metric
D2: 1N4001; D_DO-41_SOD81_P10.16mm_Horizontal
F1: RKP-SMDB050; R_1206_3216Metric
J1: USB B mini; 54819-0519_MOL
R1: 220R; R_0805_2012Metric
R2, R3: 10k; R_0805_2012Metric
R4: 1k5; R_0805_2012Metric
U1: ACS712-05B; SOIC-8_3.9x4.9mm_P1.27mm

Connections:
5V_REG: D3.2 (A), U1.1 (IP+), U1.2 (IP+); also elsewhere on the board
GND: C1.2, D2.2 (A), J1.5 (GND), R3.1, R4.1, U1.5 (GND); also elsewhere on the board
I_PWR_MEAS: U1.7 (VIOUT); also elsewhere on the board
M5V: U1.8 (VCC); also elsewhere on the board
unnamed: D1.2 (A), R1.2
unnamed: D1.1 (K), D2.1 (K), F1.2, R2.2, U1.3 (IP-), U1.4 (IP-)
unnamed: D3.1 (K), R4.2
unnamed: F1.1, J1.1 (VBUS), R1.1
unnamed: C1.1, U1.6 (FILTER)
U_PWR_MEAS: R2.1, R3.2; also elsewhere on the board

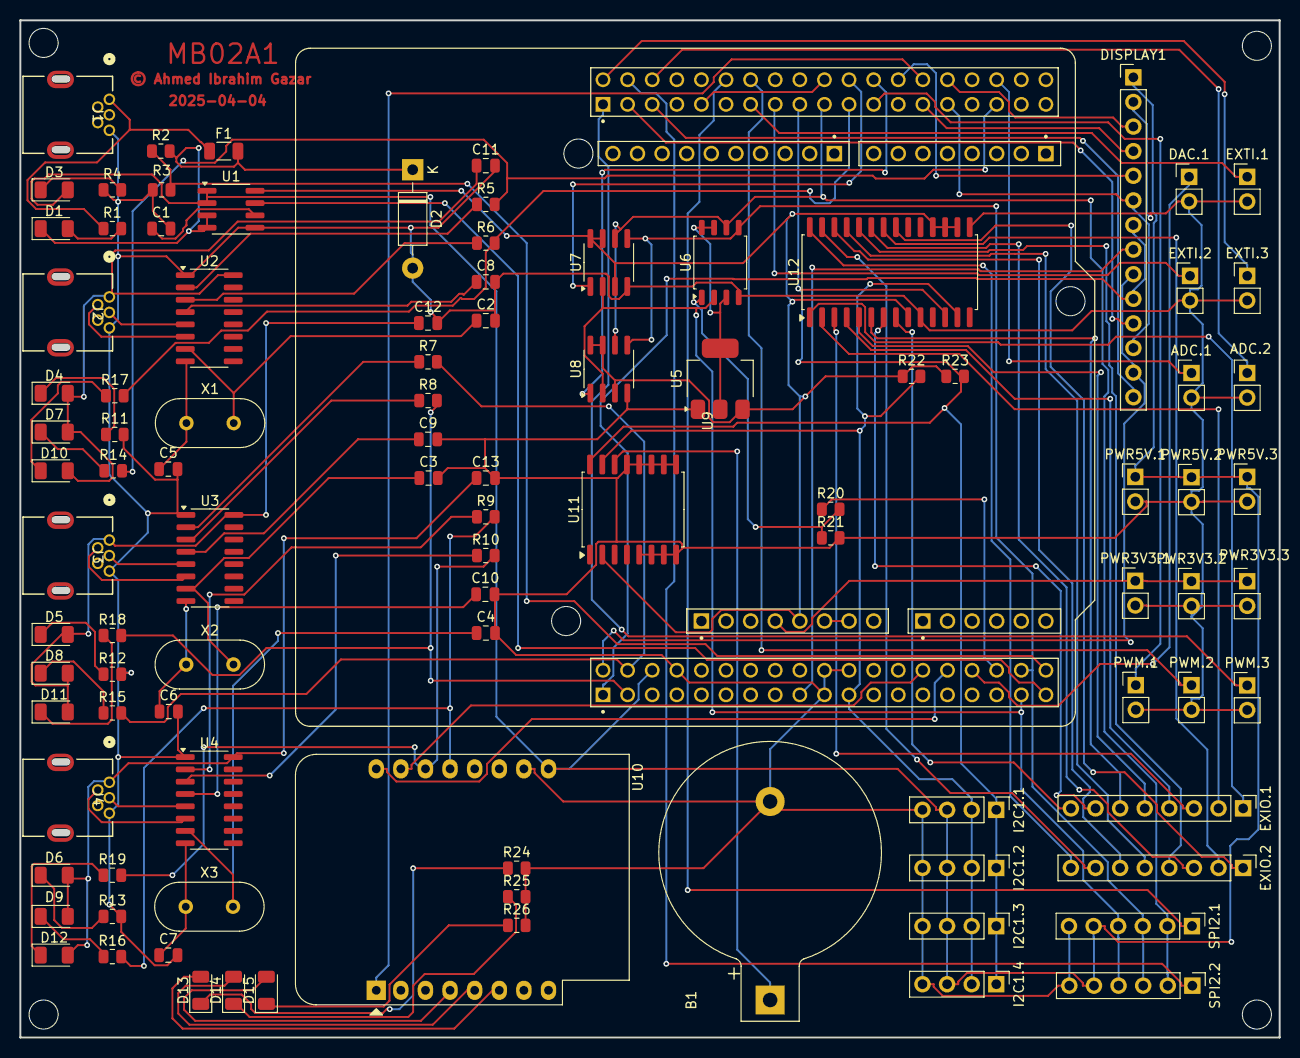
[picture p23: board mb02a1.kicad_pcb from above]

Board: 2 copper layers, 130.0 x 105.0 mm, 99 parts (0 on the bottom side), 108 nets.

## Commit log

2024-12-05 PSU01A1 design and production files added.
    [PSU_prototype.fzz]
2024-12-05 MEM01A1 design and production files added.
    [MEM_prototype.fzz]
2024-12-10 Power Supply Module prototype added.
    [PSM_prototype.fzz]
2025-03-24 Design updated.
    [conn_module.kicad_sch, cpu_module.kicad_sch, mb02a1.kicad_pcb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]
2025-03-28 Datasheets added, design updated.
    [cpu_module.kicad_sch, mb02a1.kicad_pcb, mem_module.kicad_sch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]
2025-04-05 Design update, production preparation.
    [conn_module.kicad_sch, cpu_module.kicad_sch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]
2025-04-05 Folder structure change, exported files added.
    [MEM_prototype.fzz, PSM_prototype.fzz, PSU_prototype.fzz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]

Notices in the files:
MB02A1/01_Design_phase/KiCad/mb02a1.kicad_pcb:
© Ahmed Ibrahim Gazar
